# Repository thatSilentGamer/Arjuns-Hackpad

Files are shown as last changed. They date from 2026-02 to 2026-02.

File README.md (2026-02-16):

# Arjun's Hackpad

Arjun's Hackpad is an 8-key macropad with a rotary encoder, OLED display, and underglow RGB lighting. It uses custom QMK firmware with advanced features like RGB mode cycling and a toggleable encoder with 4 different modes.

## Features

* 8-key layout (2 rows × 4 columns)
* OLED Display showing encoder mode and RGB status
* EC11 Rotary encoder with 4 switchable modes (Volume, Brightness, Media, Scroll)
* 16x SK6812 MINI-E RGB LEDs (2 per key) for vibrant underglow
* Custom QMK firmware with advanced RGB and encoder control

## CAD Model

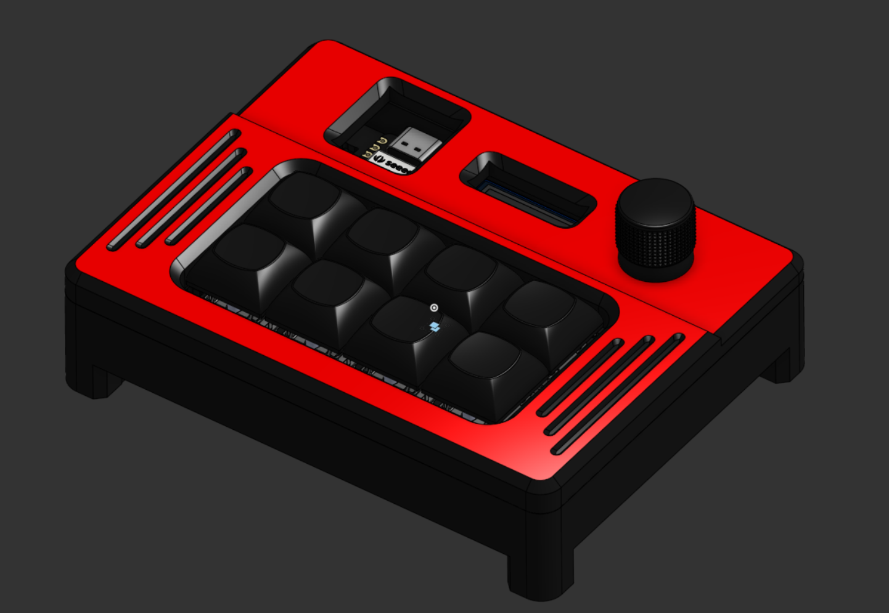
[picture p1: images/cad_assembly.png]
CAD Assembly


The case consists of two 3D printed parts held together with M3 hardware:
* **Top piece** - Contains 4 heatset inserts for mounting
* **Bottom piece** - Screws pass through bottom into top inserts
* Assembly uses 4x M3×16mm screws and 4x M3×5×4mm heatset inserts

## PCB

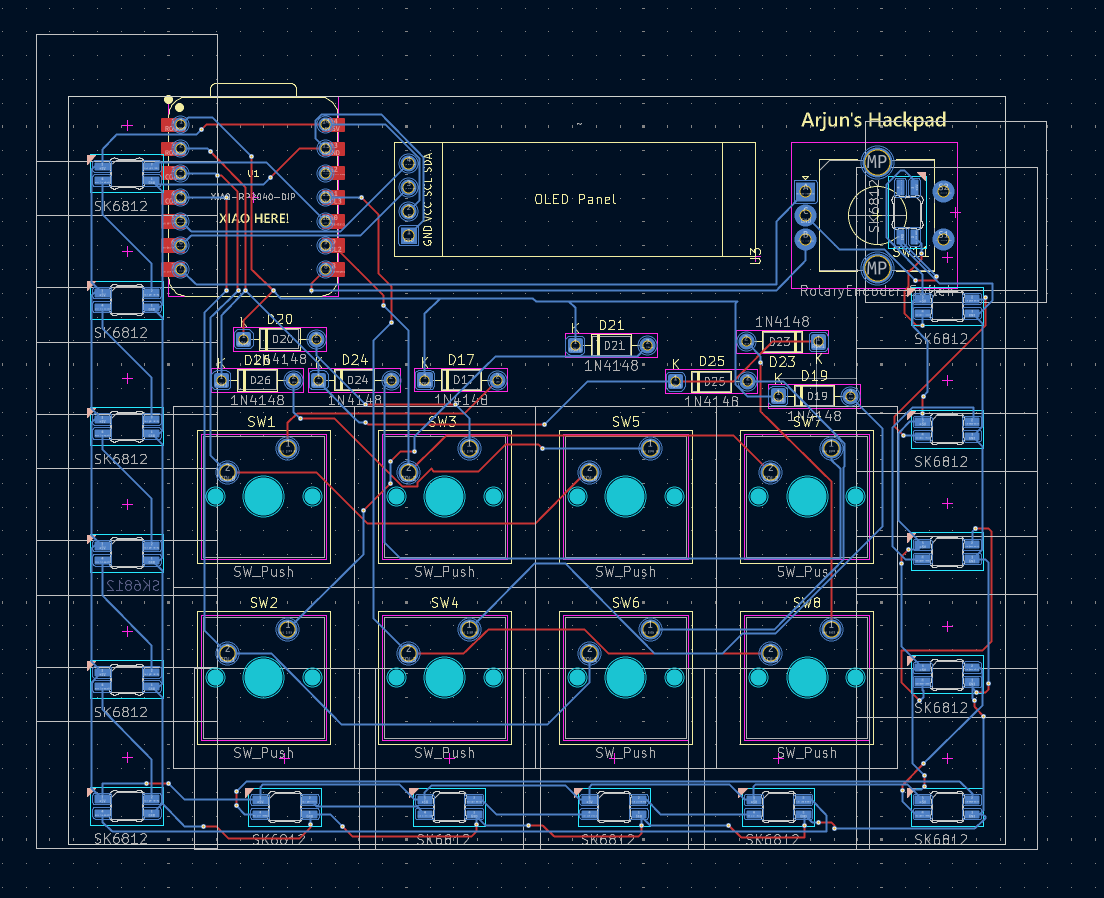
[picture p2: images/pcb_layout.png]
PCB Layout


**PCB Specifications:**
* Dimensions: 78.72mm × 98.51mm
* 2-layer design
* Matrix wired as 2 rows × 4 columns with COL2ROW diode direction
* Seeed XIAO RP2040 microcontroller

### Schematic

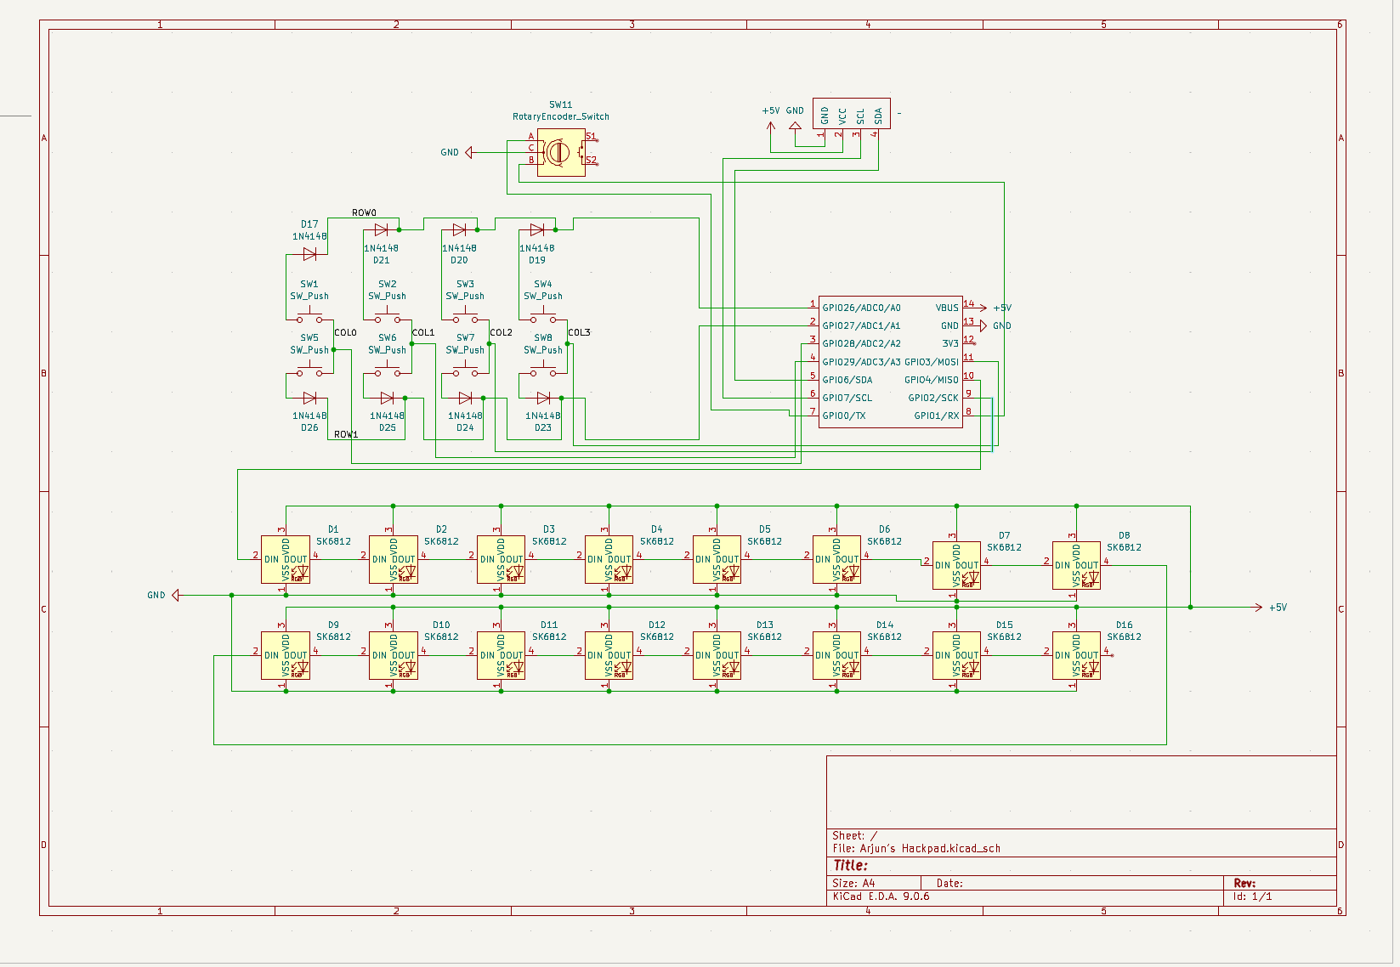
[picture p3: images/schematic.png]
Schematic


The design uses a standard keyboard matrix with diodes. RGB LEDs are chained on GPIO4, OLED uses I2C on GPIO6/GPIO7, and the rotary encoder connects to GPIO0/GPIO1.

## Firmware

This hackpad uses **QMK firmware.**

### Key Layout:
```
[RGB Cycle] [Enc Toggle] [Play/Pause] [Next Track]
[   Copy  ] [   Paste  ] [   Undo   ] [   Redo   ]
```

### Features:
* **RGB Cycle (Key 1)**: Cycles through the 10 RGB animation modes
* **Encoder Toggle (Key 2)**: Switches encoder between 4 modes:
  1. Volume Up/Down
  2. Brightness Up/Down
  3. Media Next/Previous
  4. Scroll Up/Down
* **Media Controls**: Play/Pause and Next Track
* **Editing Shortcuts**: Copy, Paste, Undo, Redo
* **OLED Display**: Shows current encoder mode and RGB status

## BOM

Here's everything you need to build this hackpad:

* 1x Seeed XIAO RP2040
* 8x MX-Style switches
* 8x White blank DSA keycaps
* 8x 1N4148 DO-35 Diodes
* 16x SK6812 MINI-E RGB LEDs
* 1x 0.91" 128x32 OLED Display
* 1x EC11 Rotary Encoder
* 4x M3×16mm screws
* 4x M3×5×4mm heatset inserts
* 1x Custom PCB
* 1x 3D printed case

## Production Files

All manufacturing files are included in the `production/` folder:
* `gerbers.zip` - PCB manufacturing files
* `firmware.hex` - Compiled QMK firmware
* `Top.step` - 3D printable top part
* `Bottom.step` - 3D printable bottom part

## Assembly Instructions

1. Print the case parts
2. Install heatset inserts into the 4 mounting holes in the top piece
3. Solder components to the PCB:
   - Diodes
   - RGB LEDs
   - OLED display
   - Rotary encoder
   - XIAO RP2040
4. Flash firmware to the XIAO RP2040
5. Install switche* into the PCB
6. Add keycaps to switches
7. Mount PCB into bottom case
8. Attach top case using 4x M3×16mm screws through bottom case part into heatset inserts

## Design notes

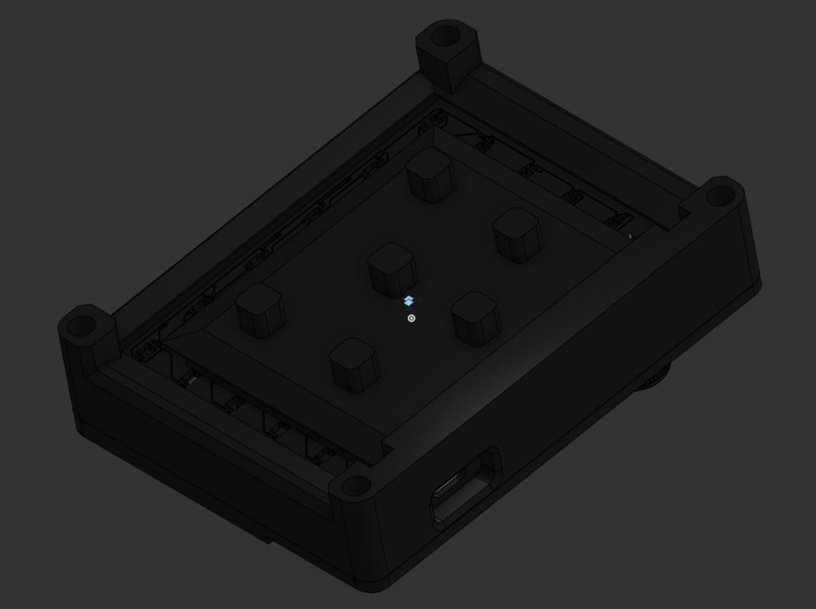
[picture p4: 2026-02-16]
images/case_bottom.png

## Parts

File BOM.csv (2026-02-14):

Item | Description | Quantity | Unit Price ($) | Total Price ($) | URL
Seeed XIAO RP2040 | Microcontroller (unsoldered through-hole) | 1 | 5.4 | 5.4 | https://www.seeedstudio.com/XIAO-RP2040-v1-0-p-5026.html
MX-Style Switches | Mechanical keyboard switches | 8 | 0.5 | 4 | https://www.digikey.com/en/products/detail/cherry-americas-llc/MX1A-11NW/20180
DSA Keycaps | Black blank DSA profile keycaps | 8 | 1 | 8 | https://pimpmykeyboard.com/dsa-1-space-pack-of-10/
1N4148 Diodes | Through-hole diodes | 8 | 0.1 | 0.8 | https://www.digikey.com/en/products/detail/onsemi/1N4148/458603
SK6812 MINI-E LEDs | RGB LEDs | 16 | 0.5 | 8 | https://www.digikey.com/en/products/detail/adafruit-industries-llc/4960/13537301
0.91" OLED Display | 128x32 OLED | 1 | 5 | 5 | https://www.amazon.com/HiLetgo-Serial-128X32-Display-Color/dp/B06XRBTBTB
EC11 Rotary Encoder | Rotary encoder | 1 | 1.5 | 1.5 | https://www.digikey.com/en/products/detail/bourns-inc/PEC11R-4215F-S0024/4499665
M3x16mm Screws | Socket head cap screws for case assembly | 4 | 0.25 | 1 | https://www.mcmaster.com/91290A126/
M3x5x4mm Heatset Inserts | Brass heatset inserts | 4 | 0.3 | 1.2 | https://www.aliexpress.us/item/2255800046543591.html
Custom PCB | 78.72mm x 98.51mm 2-layer PCB | 1 | 5 | 5
3D Printed Case | Top and Bottom parts | 1 | 10 | 10

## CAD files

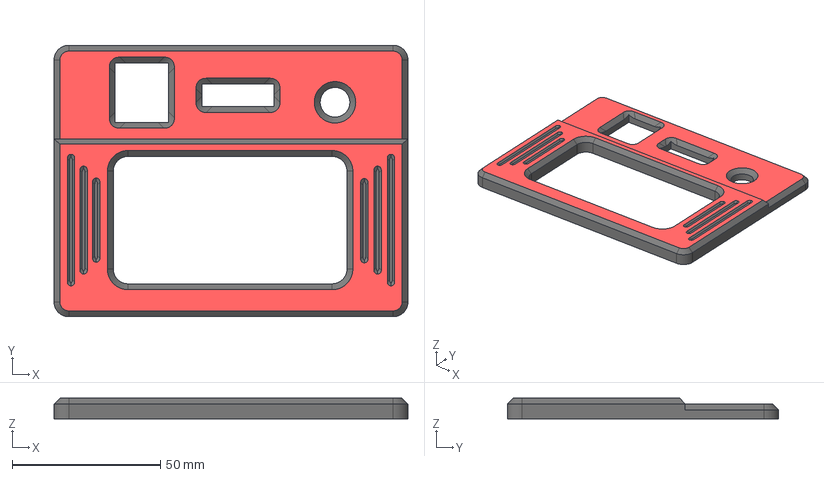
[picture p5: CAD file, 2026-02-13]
CAD/Top.step
119.5 x 91.7 x 7.00 mm

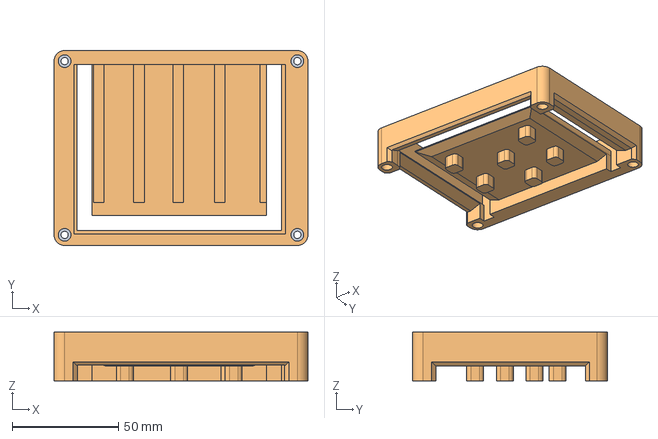
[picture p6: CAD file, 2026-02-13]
CAD/Bottom.step
119.5 x 91.7 x 23.0 mm

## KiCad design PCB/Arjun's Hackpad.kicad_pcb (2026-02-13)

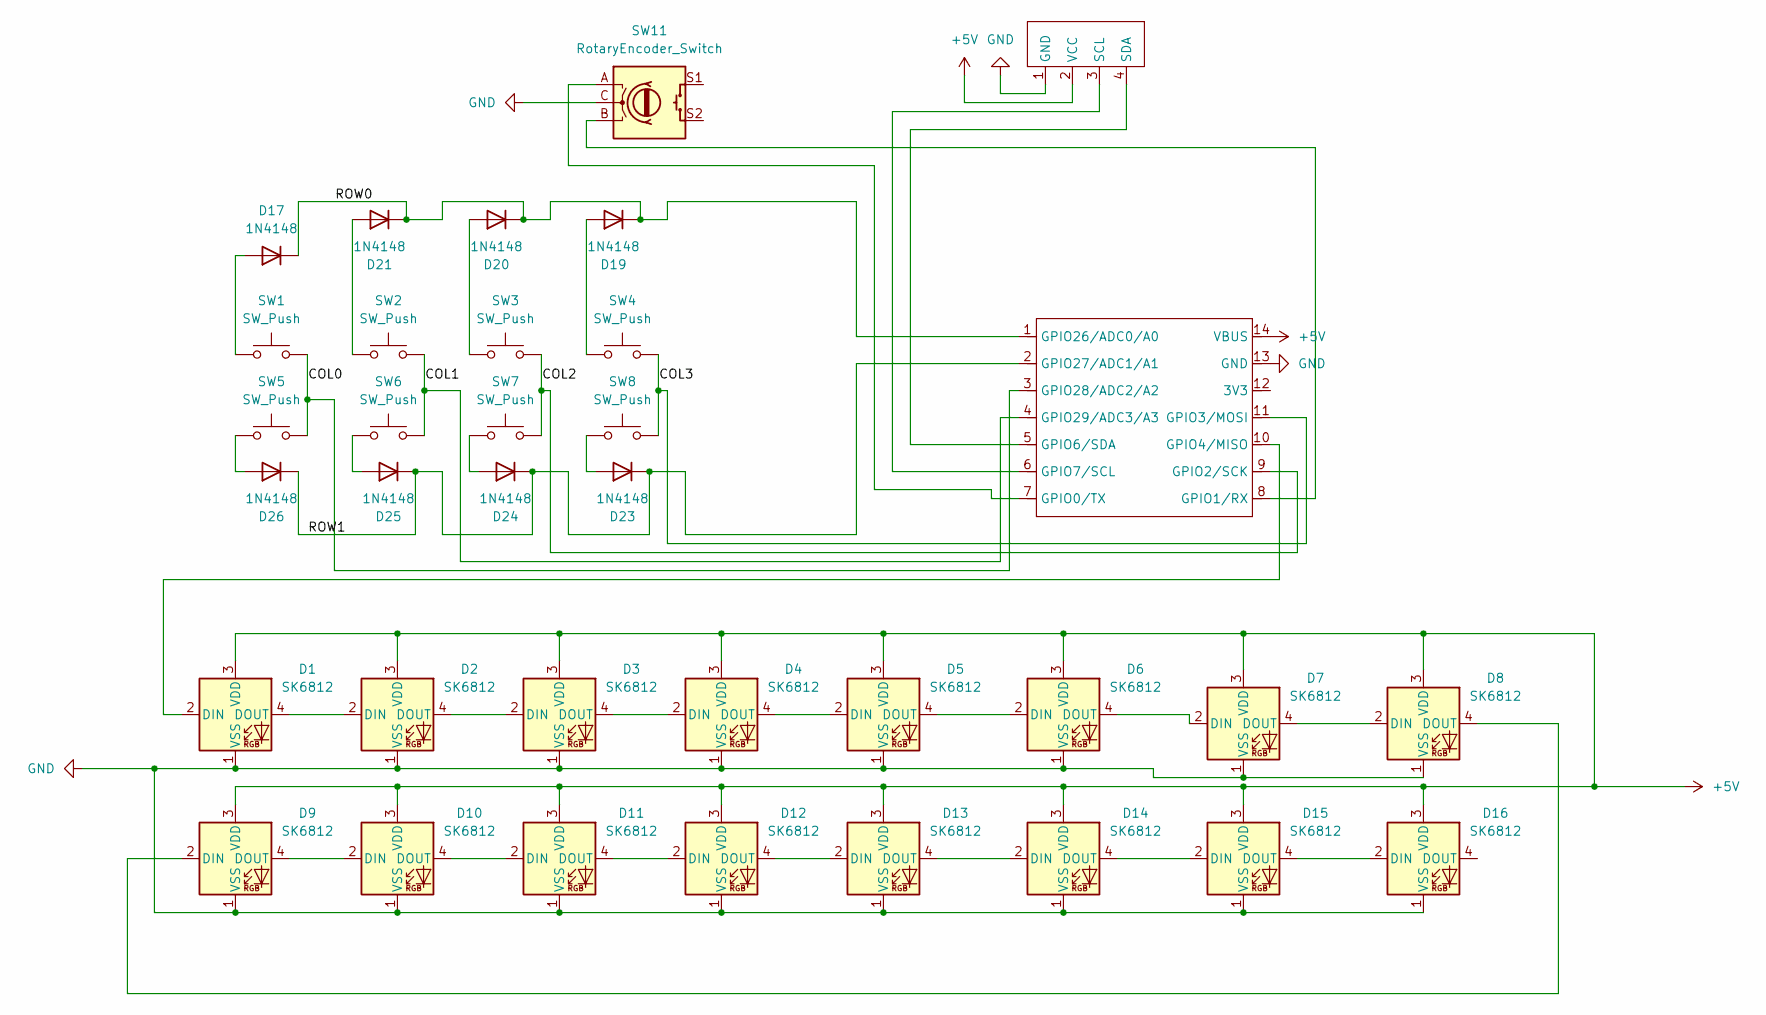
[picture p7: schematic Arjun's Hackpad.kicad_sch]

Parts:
D1, D2, D3, D4, D5, D6, D7, D8, D9, D10, D11, D12, D13, D14, D15, D16: SK6812; LED_SK6812_PLCC4_5.0x5.0mm_P3.2mm
D17, D19, D20, D21, D23, D24, D25, D26: 1N4148; D_A-405_P2.54mm_Vertical_AnodeUp
SW1, SW2, SW3, SW4, SW5, SW6, SW7, SW8: SW_Push; SW_Cherry_MX_1.00u_PCB
SW11: RotaryEncoder_Switch; RotaryEncoder_Alps_EC11E-Switch_Vertical_H20mm_CircularMoun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
U1: XIAO-RP2040-DIP
U3: SSD1306-0.91-OLED-4pin-128x32

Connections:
+5V: D1.3 (VDD), D2.3 (VDD), D3.3 (VDD), D4.3 (VDD), D5.3 (VDD), D6.3 (VDD), D7.3 (VDD), D8.3 (VDD), D9.3 (VDD), D10.3 (VDD), D11.3 (VDD), D12.3 (VDD), D13.3 (VDD), D14.3 (VDD), D15.3 (VDD), D16.3 (VDD), U1.14 (VBUS), U3.2 (VCC)
/COL0: SW1.2, SW5.2, U1.3 (GPIO28/ADC2/A2)
/COL1: SW2.2, SW6.2, U1.4 (GPIO29/ADC3/A3)
/COL2: SW3.2, SW7.2, U1.9 (GPIO2/SCK)
/COL3: SW4.2, SW8.2, U1.11 (GPIO3/MOSI)
/ROW0: D17.1 (K), D19.1 (K), D20.1 (K), D21.1 (K), U1.1 (GPIO26/ADC0/A0)
/ROW1: D23.1 (K), D24.1 (K), D25.1 (K), D26.1 (K), U1.2 (GPIO27/ADC1/A1)
GND: D1.1 (VSS), D2.1 (VSS), D3.1 (VSS), D4.1 (VSS), D5.1 (VSS), D6.1 (VSS), D7.1 (VSS), D8.1 (VSS), D9.1 (VSS), D10.1 (VSS), D11.1 (VSS), D12.1 (VSS), D13.1 (VSS), D14.1 (VSS), D15.1 (VSS), D16.1 (VSS), SW11.C, U1.13 (GND), U3.1 (GND)
unnamed: D1.2 (DIN), U1.10 (GPIO4/MISO)
unnamed: D1.4 (DOUT), D2.2 (DIN)
unnamed: D2.4 (DOUT), D3.2 (DIN)
unnamed: D3.4 (DOUT), D4.2 (DIN)
unnamed: D4.4 (DOUT), D5.2 (DIN)
unnamed: D5.4 (DOUT), D6.2 (DIN)
unnamed: D6.4 (DOUT), D7.2 (DIN)
unnamed: D7.4 (DOUT), D8.2 (DIN)
unnamed: D8.4 (DOUT), D9.2 (DIN)
unnamed: D9.4 (DOUT), D10.2 (DIN)
unnamed: D10.4 (DOUT), D11.2 (DIN)
unnamed: D11.4 (DOUT), D12.2 (DIN)
unnamed: D12.4 (DOUT), D13.2 (DIN)
unnamed: D13.4 (DOUT), D14.2 (DIN)
unnamed: D14.4 (DOUT), D15.2 (DIN)
unnamed: D15.4 (DOUT), D16.2 (DIN)
unnamed: D17.2 (A), SW1.1
unnamed: D19.2 (A), SW4.1
unnamed: D20.2 (A), SW3.1
unnamed: D21.2 (A), SW2.1
unnamed: D23.2 (A), SW8.1
unnamed: D24.2 (A), SW7.1
unnamed: D25.2 (A), SW6.1
unnamed: D26.2 (A), SW5.1
unnamed: SW11.A, U1.7 (GPIO0/TX)
unnamed: SW11.B, U1.8 (GPIO1/RX)
unnamed: U1.5 (GPIO6/SDA), U3.4 (SDA)
unnamed: U1.6 (GPIO7/SCL), U3.3 (SCL)

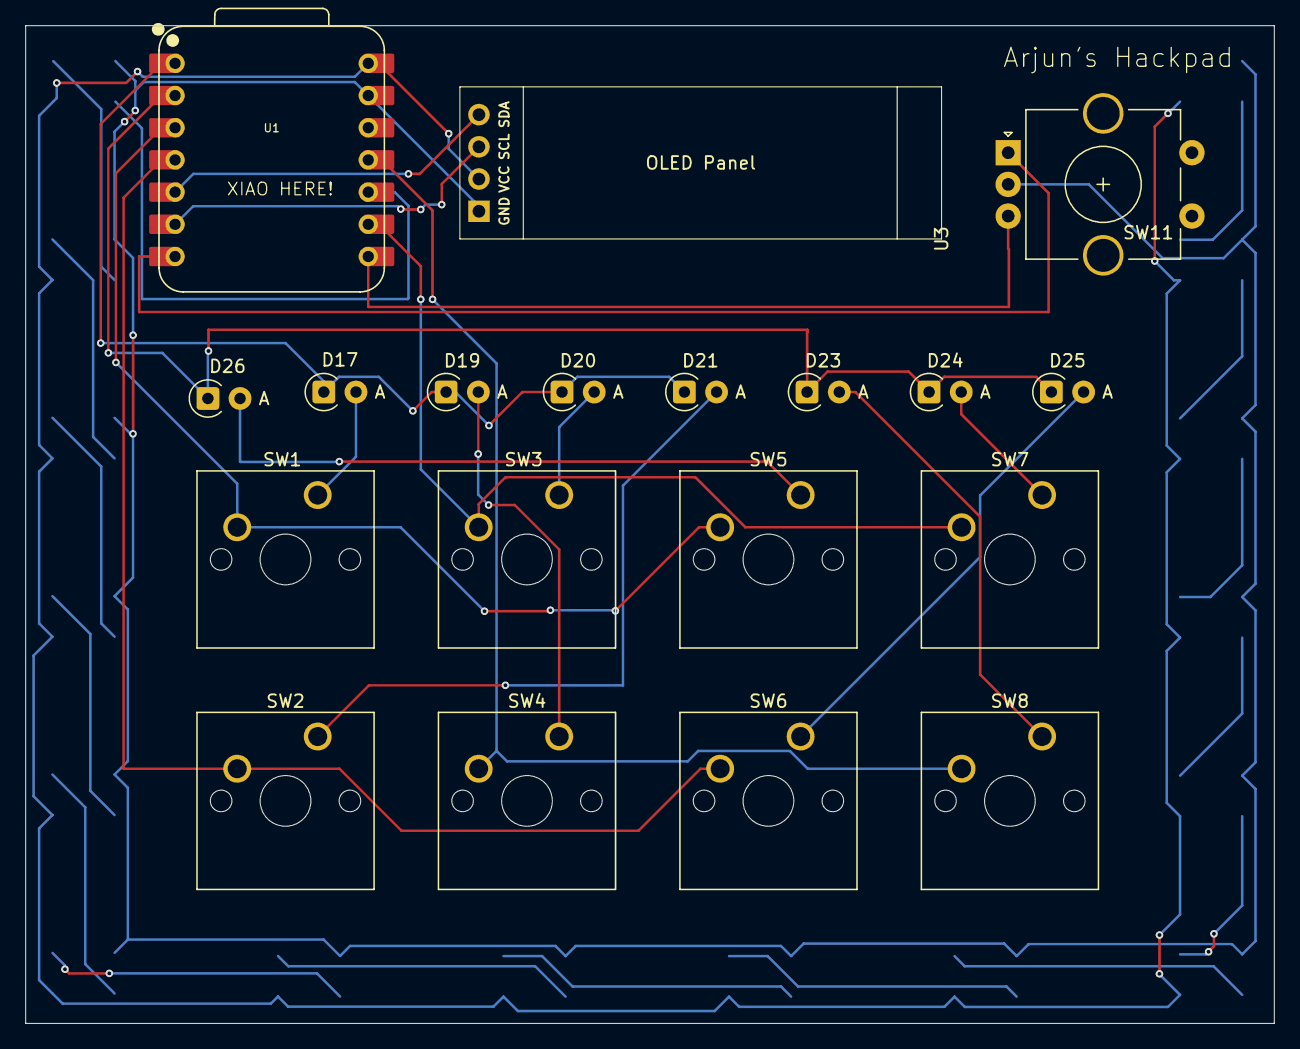
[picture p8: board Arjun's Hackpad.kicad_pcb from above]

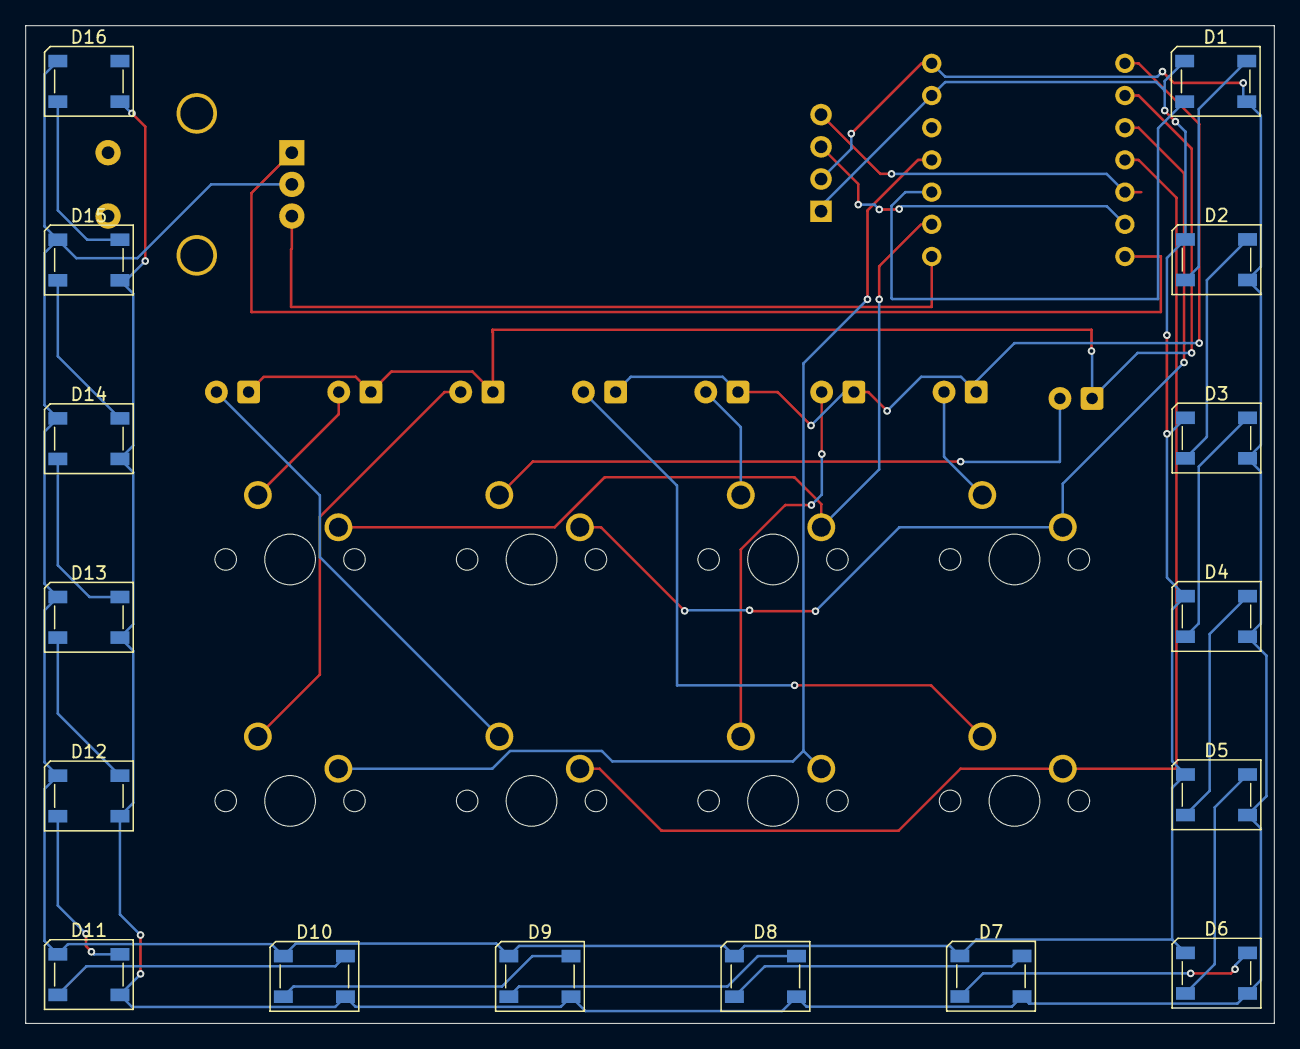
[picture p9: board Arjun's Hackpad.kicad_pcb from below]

Board: 2 copper layers, 98.5 x 78.7 mm, 35 parts (16 on the bottom side), 36 nets.

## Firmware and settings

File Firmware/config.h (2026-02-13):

#pragma once

// OLED Configuration
#define I2C_DRIVER I2CD1
#define I2C1_SDA_PIN GP6
#define I2C1_SCL_PIN GP7

// Optional: Customize OLED timeout (milliseconds)
#define OLED_TIMEOUT 30000

// Optional: OLED brightness (0-255)
#define OLED_BRIGHTNESS 128

// Optional: Flip OLED display if mounted upside down
// #define OLED_DISPLAY_180

// RGB Configuration
#define RGBLIGHT_SLEEP  // Turn off RGB when computer sleeps

// Encoder configuration
#define ENCODER_RESOLUTION 4

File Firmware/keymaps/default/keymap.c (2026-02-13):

#include QMK_KEYBOARD_H

// Custom keycodes for our special functions
enum custom_keycodes {
    RGB_CYCLE = SAFE_RANGE,  // RGB cycle including OFF
    ENC_TOG                   // Encoder mode toggle
};

// Track encoder mode (0=Volume, 1=Brightness, 2=Media, 3=Scroll)
static uint8_t encoder_mode = 0;

// Track RGB state (0=OFF, 1-10=different modes)
static uint8_t rgb_mode_state = 1;

const uint16_t PROGMEM keymaps[][MATRIX_ROWS][MATRIX_COLS] = {
    [0] = LAYOUT(
        RGB_CYCLE,  ENC_TOG,     KC_MPLY,        KC_MNXT,
        C(KC_C),    C(KC_V),     C(KC_Z),        C(S(KC_Z))
    )
};

// Handle custom keycodes
bool process_record_user(uint16_t keycode, keyrecord_t *record) {
    switch (keycode) {
        case RGB_CYCLE:
            if (record->event.pressed) {
                rgb_mode_state++;
                if (rgb_mode_state > 10) {  // 10 modes + OFF = 11 total states
                    rgb_mode_state = 0;
                }
                
                if (rgb_mode_state == 0) {
                    // Turn OFF
                    rgblight_disable();
                } else {
                    // Turn on and set mode
                    if (!rgblight_is_enabled()) {
                        rgblight_enable();
                    }
                    rgblight_mode(rgb_mode_state);
                }
            }
            return false;
            
        case ENC_TOG:
            if (record->event.pressed) {
                encoder_mode = (encoder_mode + 1) % 4;  // Cycle through 4 modes
            }
            return false;
    }
    return true;
}

// Handle encoder rotation based on current mode
bool encoder_update_user(uint8_t index, bool clockwise) {
    if (index == 0) {
        switch (encoder_mode) {
            case 0:  // Volume mode
                if (clockwise) {
                    tap_code(KC_VOLU);
                } else {
                    tap_code(KC_VOLD);
                }
                break;
                
            case 1:  // Brightness mode
                if (clockwise) {
                    tap_code(KC_BRIU);
                } else {
                    tap_code(KC_BRID);
                }
                break;
                
            case 2:  // Media mode
                if (clockwise) {
                    tap_code(KC_MNXT);
                } else {
                    tap_code(KC_MPRV);
                }
                break;
                
            case 3:  // Scroll mode
                if (clockwise) {
                    tap_code(KC_WH_D);
                } else {
                    tap_code(KC_WH_U);
                }
                break;
        }
    }
    return false;
}

#ifdef OLED_ENABLE
bool oled_task_user(void) {
    // Display hackpad title
    oled_write_P(PSTR("HACKPAD v1.0\n"), false);
    oled_write_P(PSTR("------------\n"), false);
    
    // Display encoder mode
    oled_write_P(PSTR("Encoder: "), false);
    switch (encoder_mode) {
        case 0:
            oled_write_P(PSTR("Volume\n"), false);
            break;
        case 1:
            oled_write_P(PSTR("Brightness\n"), false);
            break;
        case 2:
            oled_write_P(PSTR("Media\n"), false);
            break;
        case 3:
            oled_write_P(PSTR("Scroll\n"), false);
            break;
    }
    
    // Display RGB status
    oled_write_P(PSTR("\nRGB: "), false);
    if (rgb_mode_state == 0) {
        oled_write_P(PSTR("OFF"), false);
    } else {
        oled_write_P(PSTR("Mode "), false);
        oled_write(get_u8_str(rgb_mode_state, ' '), false);
    }
    
    return false;
}
#endif

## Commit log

2026-02-13 Add complete project files and documentation
    [Arjun's Hackpad.kicad_pcb, Arjun's Hackpad.kicad_sch, Bottom.step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]
2026-02-14 Add BOM
    [BOM.csv]
2026-02-14 Update project files
    [BOM.csv]
2026-02-16 Add CAD source files and updated gerbers with corrected footprints
    [Bottom.step, Top.step]
2026-02-16 Add updated images of cad and pcb
